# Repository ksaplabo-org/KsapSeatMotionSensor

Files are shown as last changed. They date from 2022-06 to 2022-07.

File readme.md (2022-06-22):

# SeatMotionSensor

## 目次  
- [全体概要](#content1)  
- [ESP32で人感センサの操作](#content2)  
- [Raspberry Piでデータ送受信](#content3)  
- [モノの作成](#content4)  
- [DynamoDBの作成](#content5)  
- [IAMロールの作成](#content6)  
- [Lambdaの作成](#content7)  
- [API Gatewayの作成](#content8)  
- [公開するWebアプリケーションの作成](#content9)  
- [S3での公開方法](#content10)  
- [残課題](#content11)  
- [感圧センサの利用](#content12)

<h2 id="content1">全体概要</h2>  

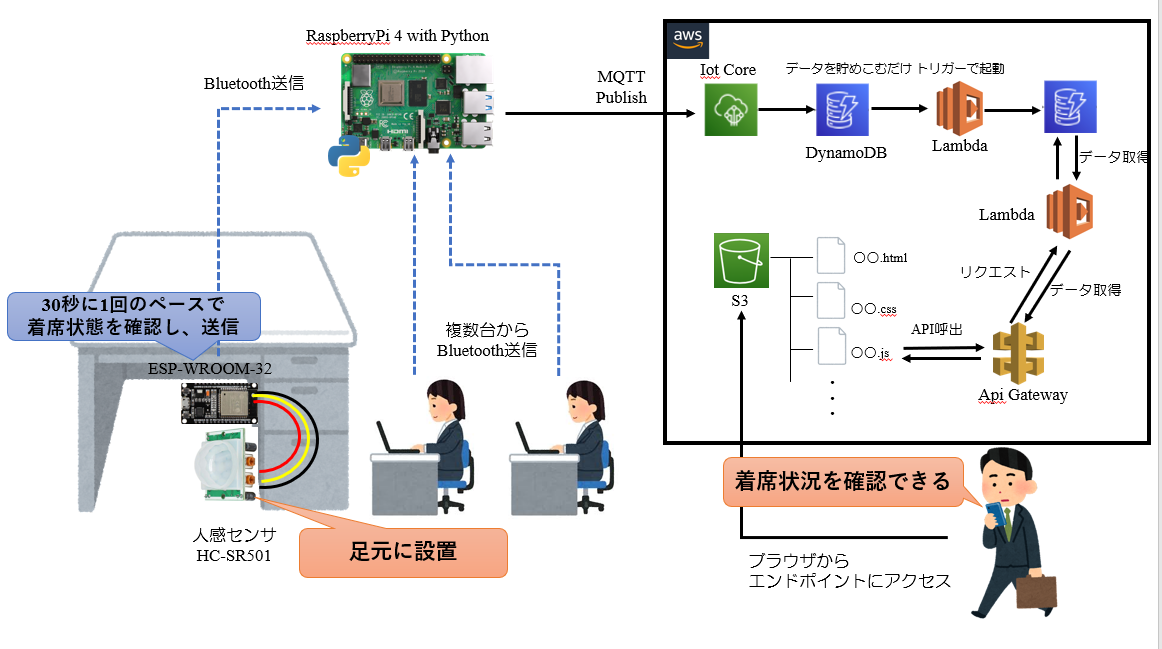
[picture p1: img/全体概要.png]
全景
  

支店管理部の在籍情報をリアルタイムで知ることができるシステムの開発  

※以下は人感センサを利用したシステムの説明を行う  
※一部ソースは感圧センサを利用したコーディングとなっているため  
  人感センサを利用したソースはHistoryから参照  

・システム説明  
図の左半分：管理部の座席足元に人感センサを設置して、席にいるかどうかをESP32でキャッチ  
           着席情報をRaspberry Piへ送信  
           それを受け取ったRaspberry PiがIoT Coreへパブリッシュする  

図の右半分：IoT Coreの受信をトリガーに、DynamoDBへ日時をキーとしてデータ登録  
           このデータ登録をトリガーとして、もう一つのDynamoDBに座席名をキーとしてデータ登録  
           S3の静的ホスティングサービスを使い、公開されたURLに利用者はアクセスする。  
           S3に保存してある、JavaScriptからAPIGateway、Lambdaを介して在籍情報を取得  
           データを成形して、ブラウザ上に表示する  

文章での説明では分かりずらいので、それぞれの機能実装手順を以下に示す  

<h2 id="content2">ESP32で人感センサの操作</h2>  

人感センサの仕組みについては[こちら](./%E6%8A%80%E8%A1%93%E8%AA%BF%E6%9F%BB.md)を参照  

ESP32と人感センサの配線は以下のように組む  
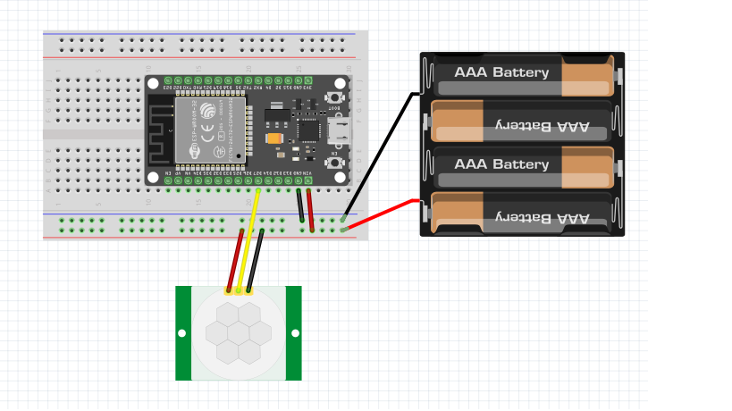
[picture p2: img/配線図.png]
配線図
  

ソースは以下のようになる  
[seatmotionsensor.ino](./ino/seatmotionsensor.ino)  

Arduino IDEを使用して、ソースをコンパイルする  
Arduino IDEの使い方は[こちら](https://github.com/ksaplabo-org/ksapDoorOpener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)を参照  

<h2 id="content3">Raspberry Piでデータ送受信</h2>  

Raspberry Piのセットアップは[こちら](https://github.com/ksaplabo-org/Raspi-Setup)を参照  

各ライブラリのインストールが必要  
- MQTT通信するためのライブラリ  
```
$ pip3 install paho-mqtt python-etcd
```
- bluetoothを使用するためのライブラリ  
```
$ sudo apt-get install python3-pip libglib2.0-dev
$ sudo pip3 install bluepy
```

ソースは以下のようになる  
[logget.py](./py/logger.py)  
[main.py](./py/main.py)  
[motion_detector.py](./py/motion_detector.py)  

<h2 id="content4">モノの作成</h2>  
 
Iot Coreで「モノ」の作成  
作成方法については[こちら](https://github.com/ksaplabo-org/aircondition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)を参照  
モノの名前は任意で作成  

MQTTテストクライアントで受信するとこを確認出来たら、DynamoDBの作成を行う  

<h2 id="content5">DynamoDBの作成</h2>

今回はDynamoDBを2つ用意する。  
1.受信したデータを全て登録するDynamoDB  
2.座席名ごとに着席情報を管理するDynamoDB  

1.受信したデータを全て登録するDynamoDB  

DynamoDBを作成方法は[こちら](https://github.com/ksaplabo-org/aircondition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)を参照  
今回作成するDynamoDB名は以下の通り ※名前は任意  
DynamoDB名：ksap-seatingstatehistory-tbl  

DynamoDBのコンソール画面から「テーブル」＞「項目の探索」を選択し  
作成したDynamoDBを選択  
「項目の作成」を選択して、以下のテストデータを作成  

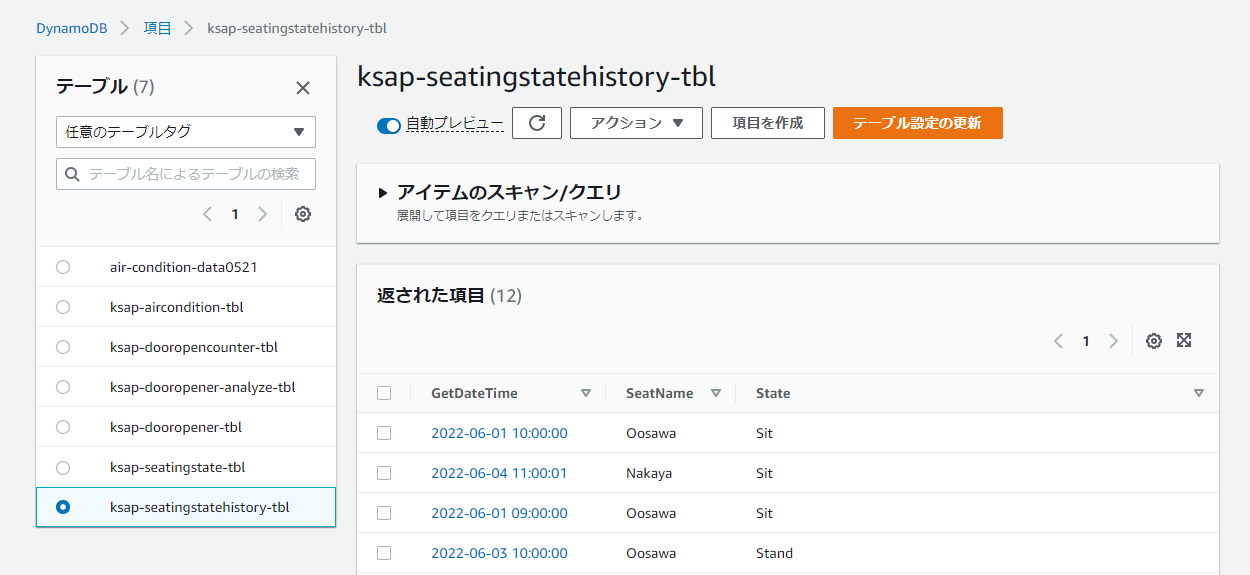
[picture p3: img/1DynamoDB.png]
1DynamoDB
  

項目名は任意だが、この後のソースでこの名前を使用するため後で迷わないように  

2.座席名ごとに着席情報を管理するDynamoDB  

1と同様の手順でテストデータまで作成  
DynamoDB名：ksap-seatingstate-tbl  

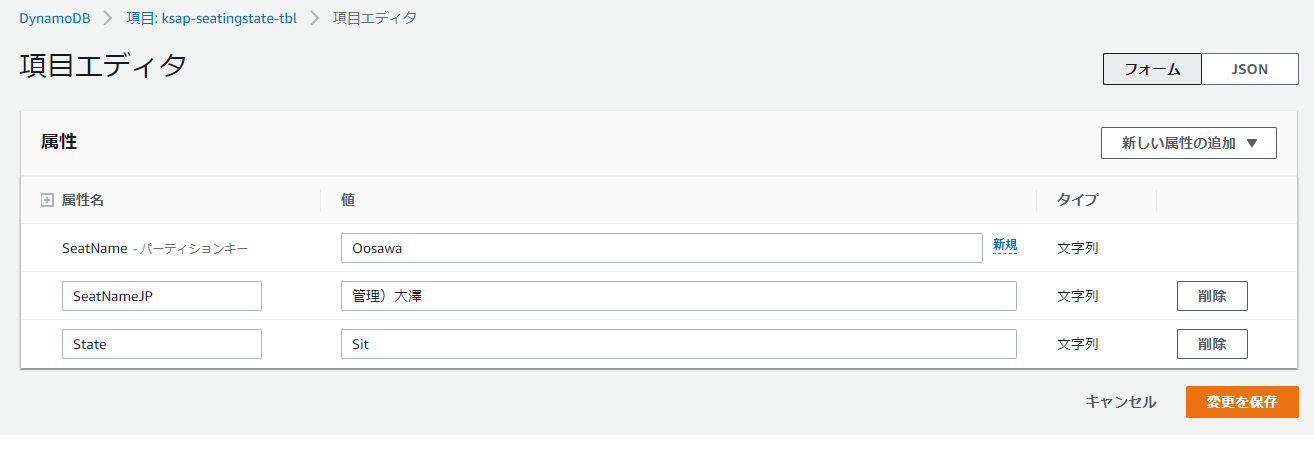
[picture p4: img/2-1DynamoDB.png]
2-1DynamoDB
  
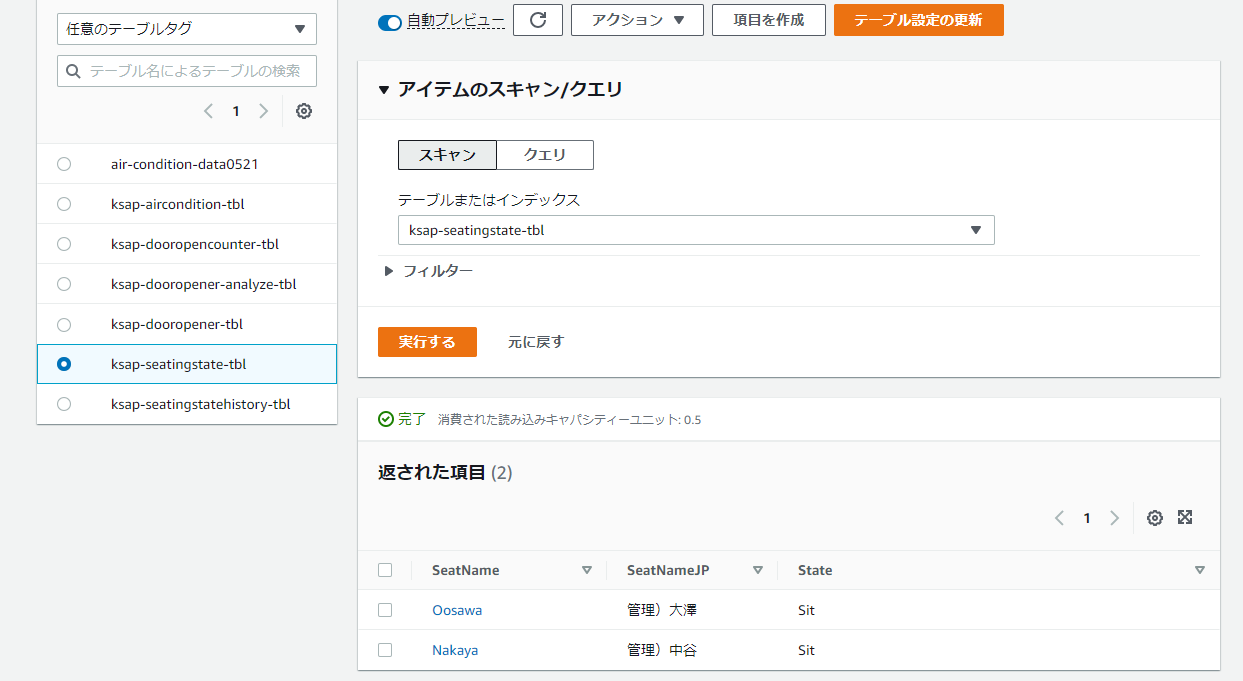
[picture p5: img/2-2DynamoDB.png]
2-2DynamoDB
  

<h2 id="content6">IAMロールの作成</h2>

LambdaがDynamoDBにアクセスするためのIAMロールを作成  

IAMコンソール画面の左ペインから「ロールを選択」  
「ロール」の設定画面から「ロールの作成」ボタンを選択  
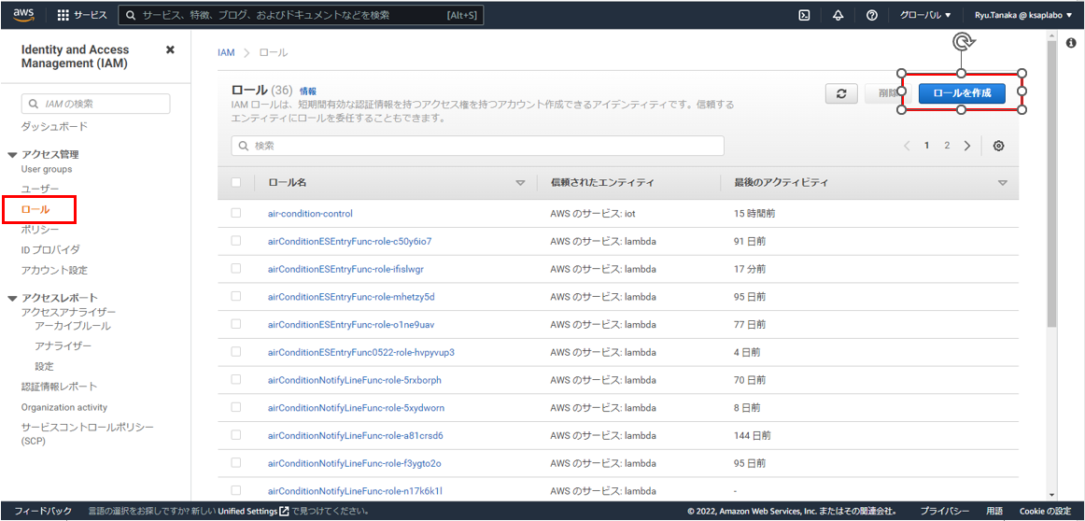
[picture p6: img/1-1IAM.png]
1-1IAM
  

「信頼されたエンティティタイプ」はデフォルトの「AWSのサービス」を選択  
「ユースケース」は「Lambda」を選択し、「次へ」を選択  
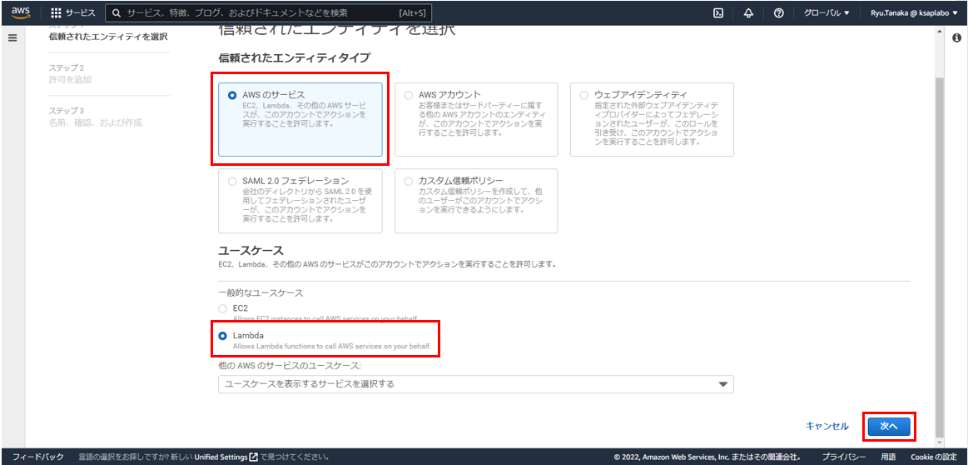
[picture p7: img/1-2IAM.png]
1-2IAM
  

「許可を追加」画面で以下の二つのポロしーを選択して、「次へ」を選択  
・AmazonDynamoDBFullAccess  
・AWSLambdaDynamoDBExecutionRole  
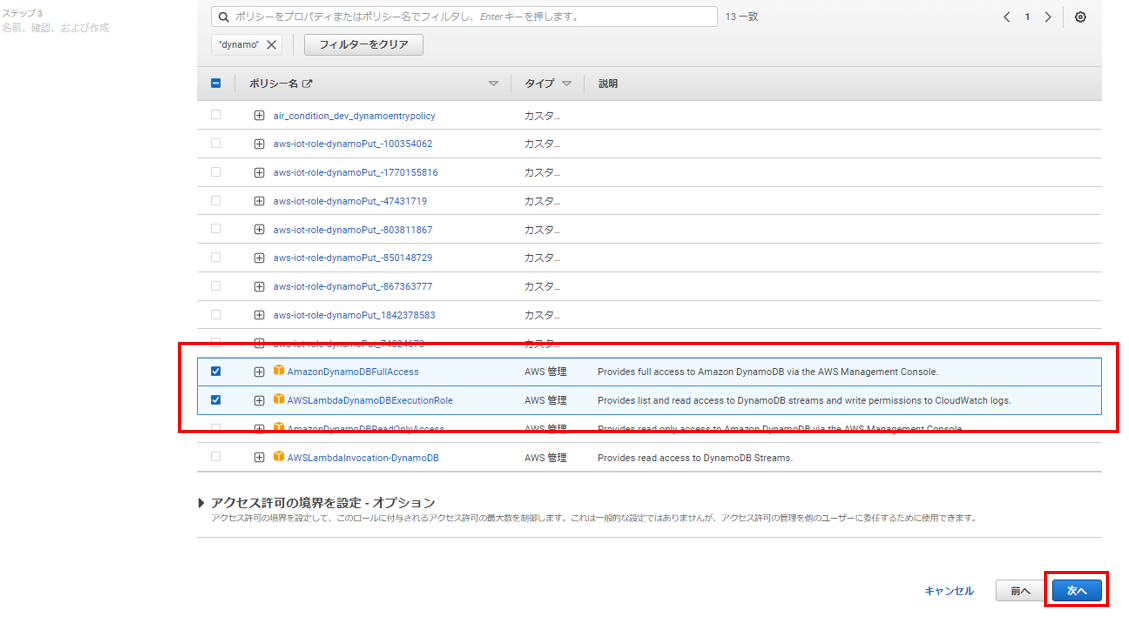
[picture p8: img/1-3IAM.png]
1-3IAM
  

「ロール名」に「LambdaAccess2DynamoDB」と入力し、右下の「ロールを作成」を選択  
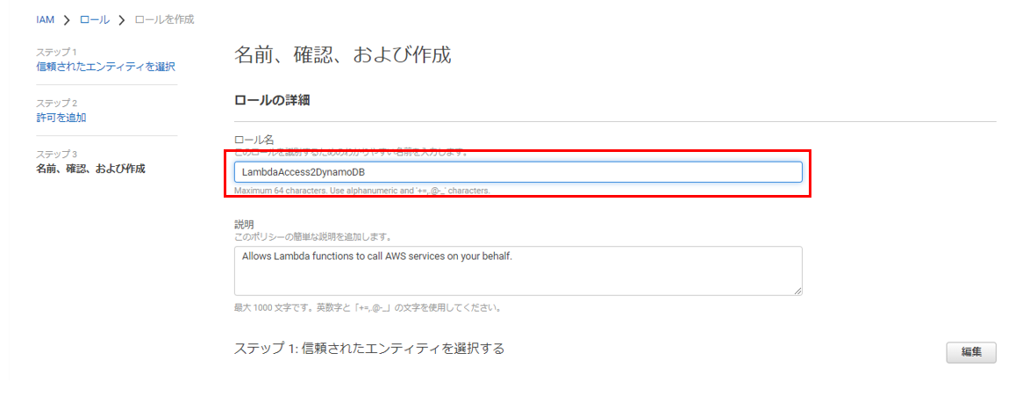
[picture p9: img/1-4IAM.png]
1-4IAM
  
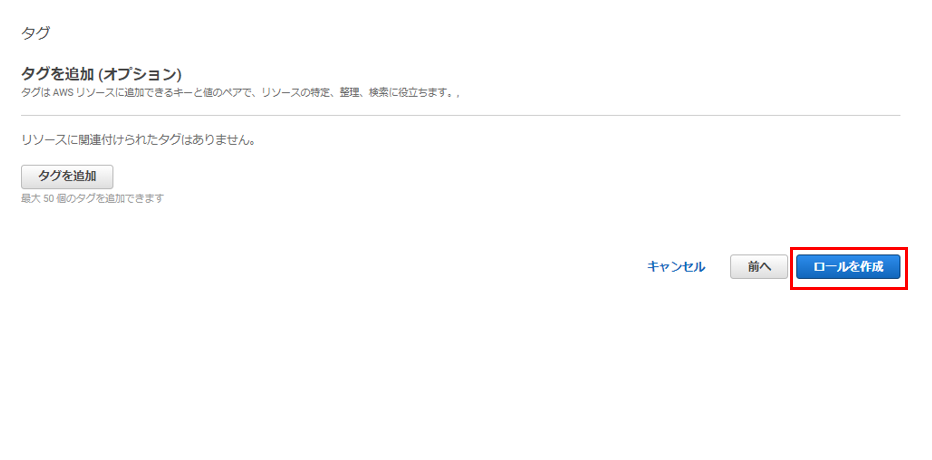
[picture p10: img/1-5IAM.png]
1-5IAM
  

ロールの作成が完了するとロールの一覧に「LambdaAccess2DynamoDB」が登録されます  
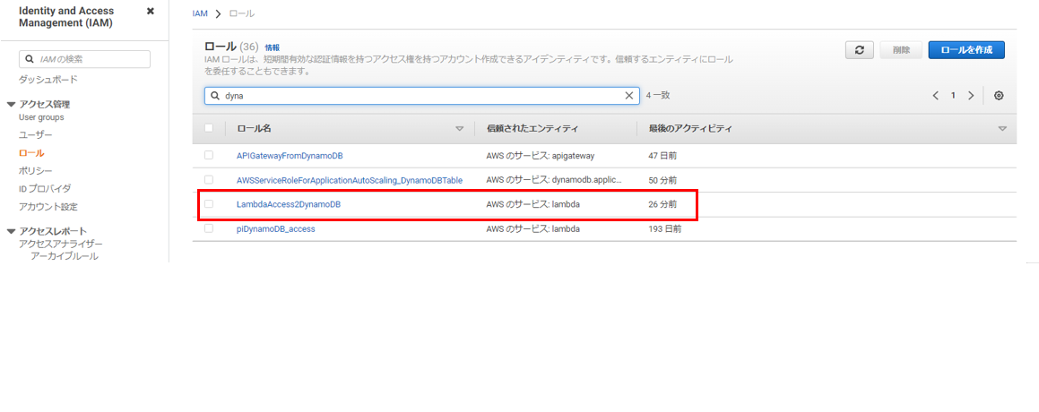
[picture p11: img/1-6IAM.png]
1-6IAM
  

<h2 id="content7">Lambdaの作成</h2>

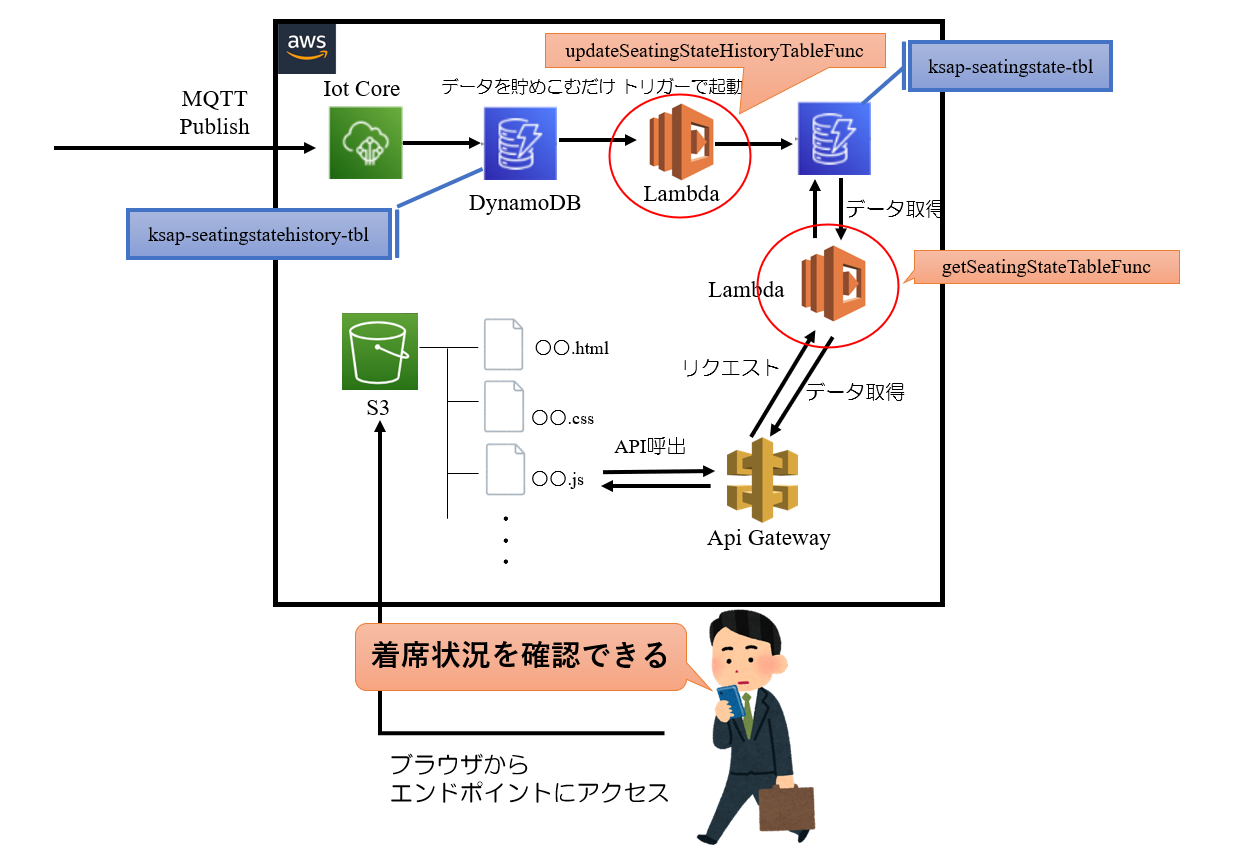
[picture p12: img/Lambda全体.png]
Lambda全体
  

Lambdaを2つ用意する  

1.ksap-seatingstatehistory-tblへのデータ登録をトリガーに  
SeatNameをキーにして、ksap-seatingstate-tblにデータをUpdateする関数  
(関数名：updateSeatingStateHistoryTableFunc)  

2.APIGatewayからのリスエストをトリガーに  
ksap-seatingstate-tblのデータを取得する関数  
(関数名：getSeatingStateTableFunc)  

1.updateSeatingStateHistoryTableFunc  

Lambdaコンソールから「関数の作成」を選択  
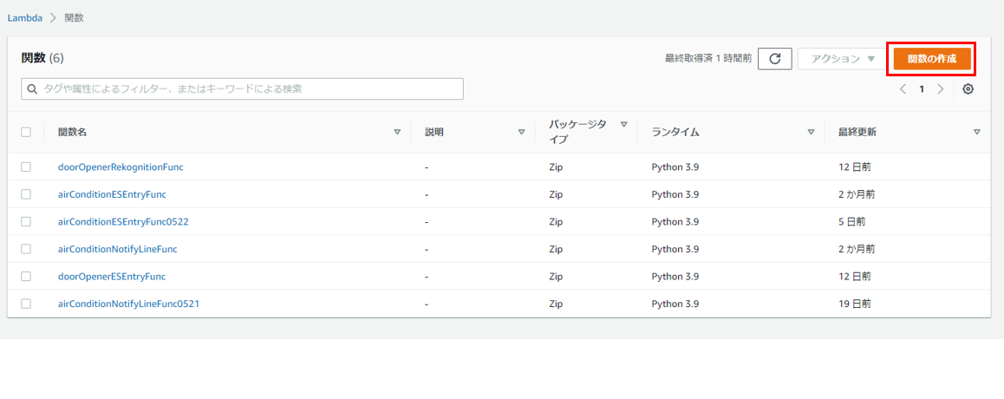
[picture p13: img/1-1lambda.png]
1-1lambda
  

オプションはデフォルトの「一から作成」を選択  
関数名は「updateSeatingStateHistoryTableFunc」を入力  
ランタイムは「Python3.9」を選択  
アーキテクチャはデフォルトのまま  
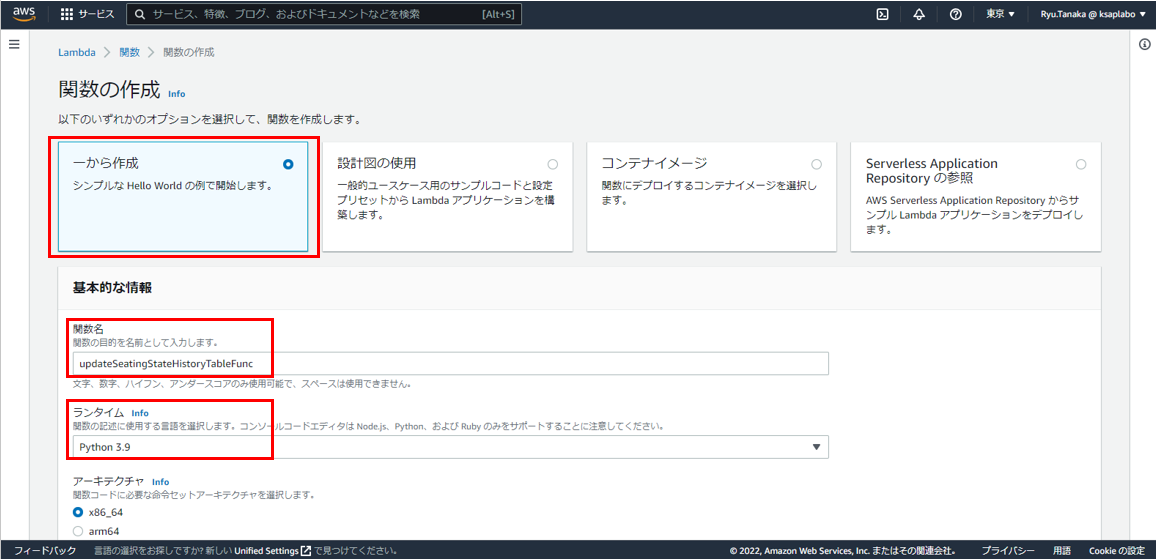
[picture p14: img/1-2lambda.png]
1-2lambda
  

「デフォルトの実行ロールの変更」を開き  
「既存のロールを使用する」を選択  
既存ロールの一覧から先ほど作成した「LambdaAccess2DynamoDB」を選択  
詳細設定はそのままで、関数の作成を選択  
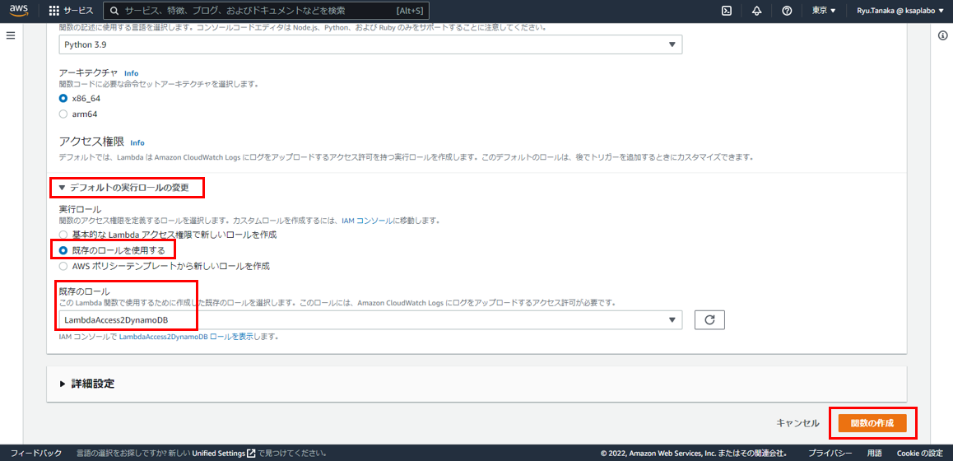
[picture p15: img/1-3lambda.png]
1-3lambda
  

「コードソース」に以下のソースをコピーして貼り付けする  
[updateSeatingStateHistoryTableFunc.py](./lambda/updateSeatingStateHistoryTableFunc.py)  
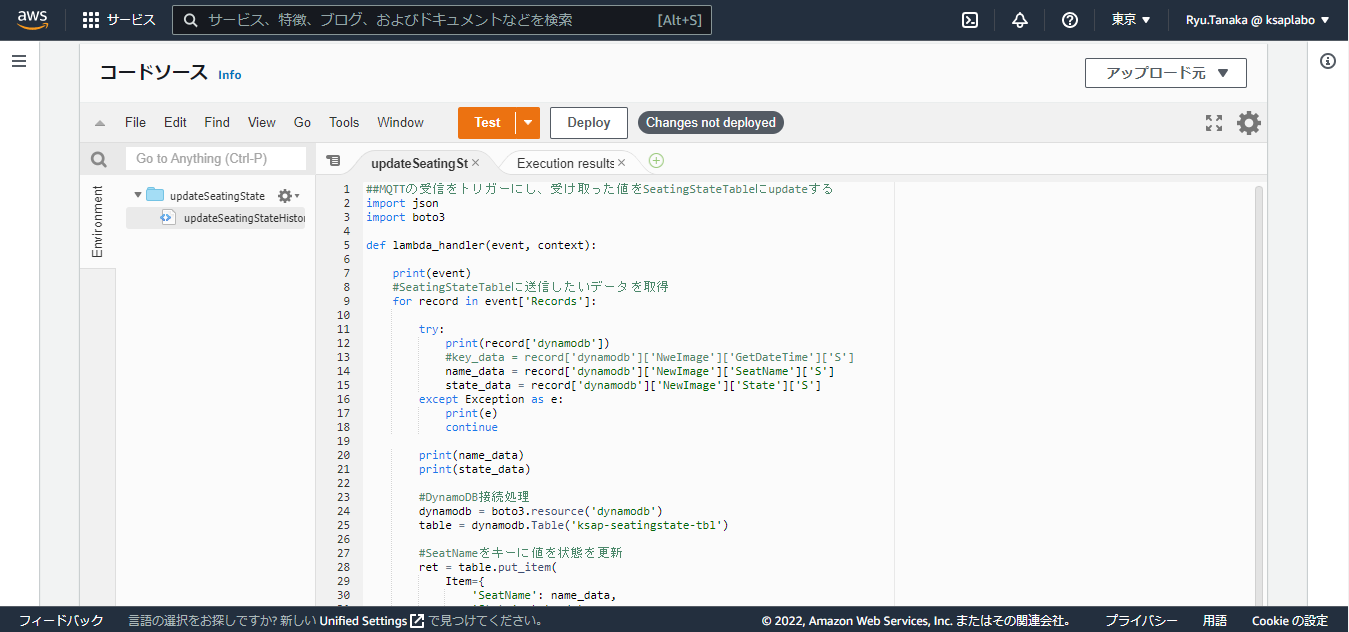
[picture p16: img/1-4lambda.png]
1-4lambda
  

ソースを作り終えたら、トリガーの設定を行う  
「設定」タブを選択し、「トリガーを追加」を選択  
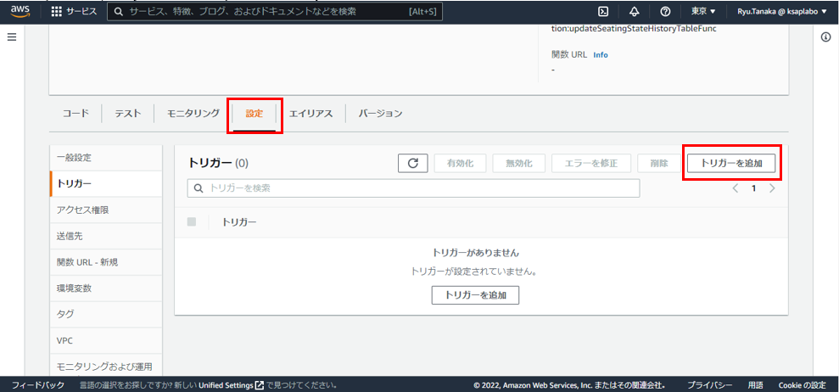
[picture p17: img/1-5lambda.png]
1-5lambda
  

「トリガーを選択」のプルダウンから「DynamoDB」を選択し  
「DynamoDBテーブル」は「ksap-seatingstatehistory-tbl」を選択  
後の設定はデフォルトのまま、右下の「追加」を選択  
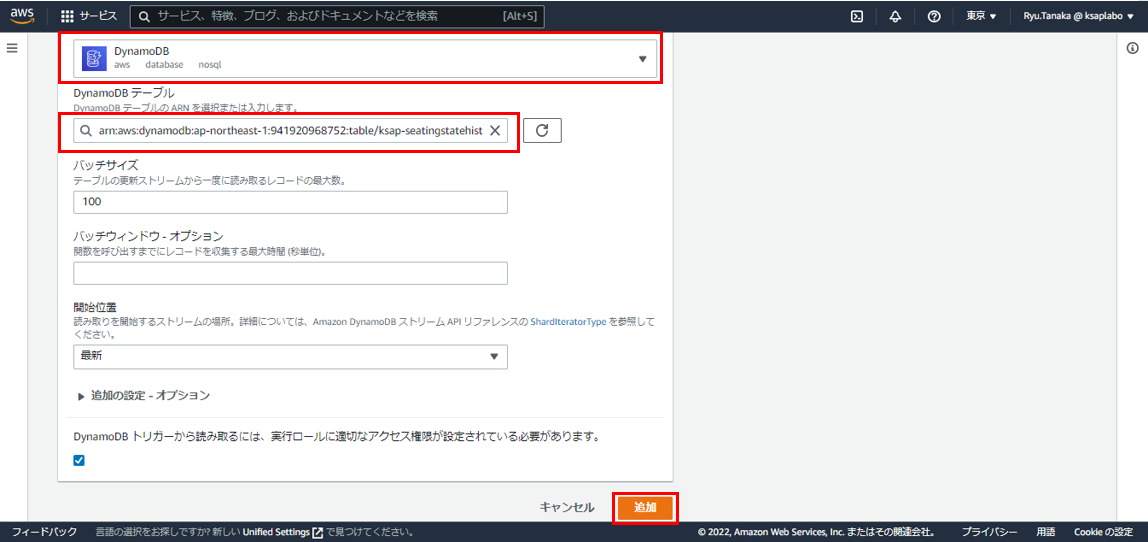
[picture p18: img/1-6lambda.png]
1-6lambda
  

関数の定義画面に戻るので、そこでDynamoDBがトリガーに追加されています  
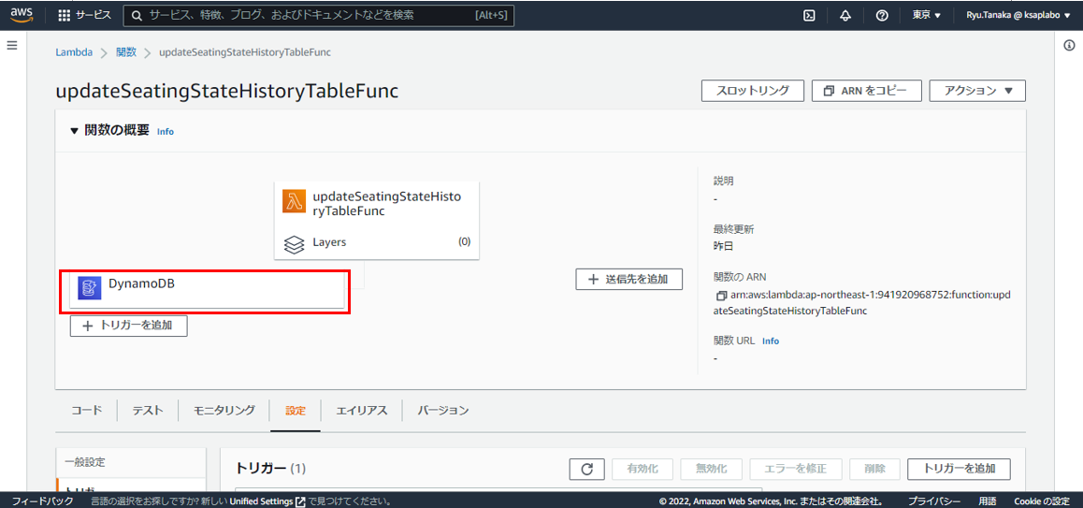
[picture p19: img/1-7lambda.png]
1-7lambda
  

以上で1つ目の関数の作成は終わり  

<br>
2.getSeatingStateTableFunc  

updateSeatingStateHistoryTableFuncと同様の出順で作成  
※関数名「getSeatingStateTableFunc」とする  
※トリガーにDynamoDBの登録はしません  
以下のソースをコピペしてください  
[getSeatingStateTableFunc.py](./lambda/getSeatingStateTableFunc.py)  

<h2 id="content8">API Gatewayの作成</h2>

lambda関数「getSeatingStateTableFunc」へリクエストするためのGatewayを作成します  

コンソール画面から「APIを作成」を選択  
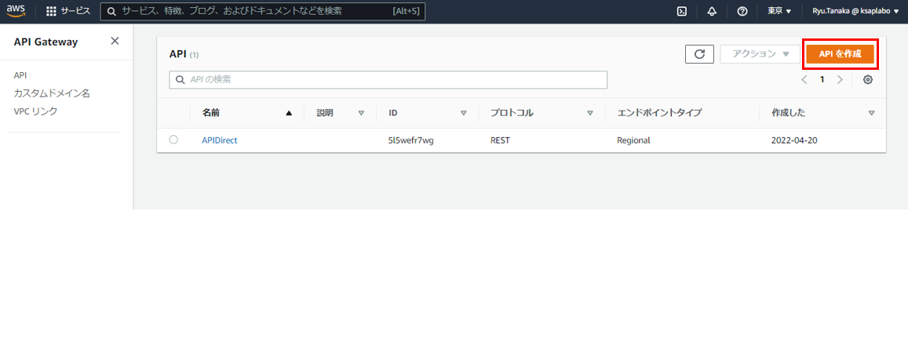
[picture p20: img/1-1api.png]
1-1api
  

APIタイプを選択の中の上から3つ目の「REST API」を選択  
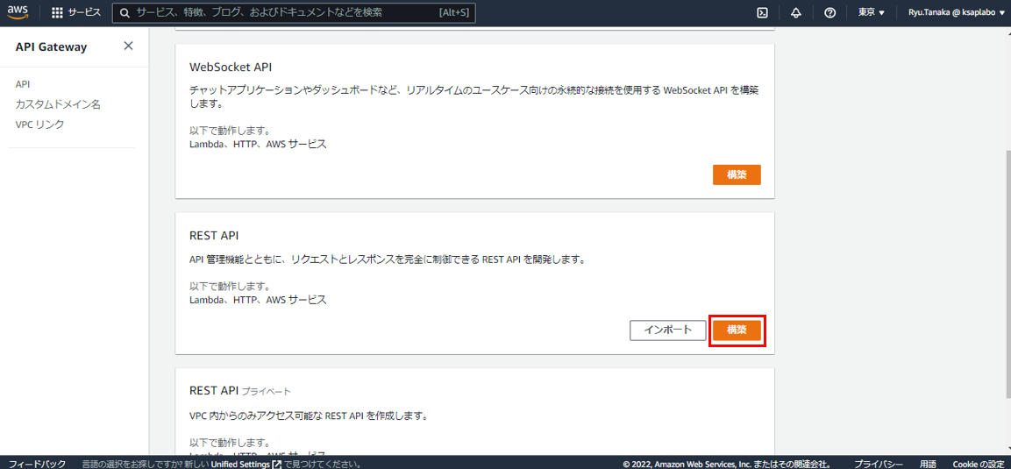
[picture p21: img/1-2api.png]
1-2api
  

API名を「SeatMotionAPI」とし、他の設定はデフォルトのまま「APIの作成」を選択  
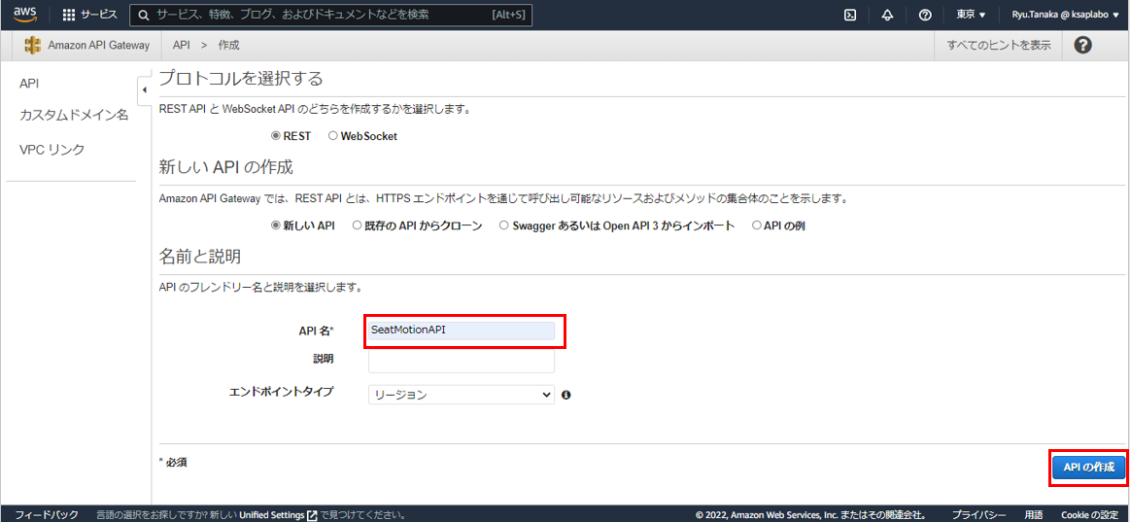
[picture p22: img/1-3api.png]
1-3api
  

画面が遷移したら、アクションから「リソースの作成」を選択　　
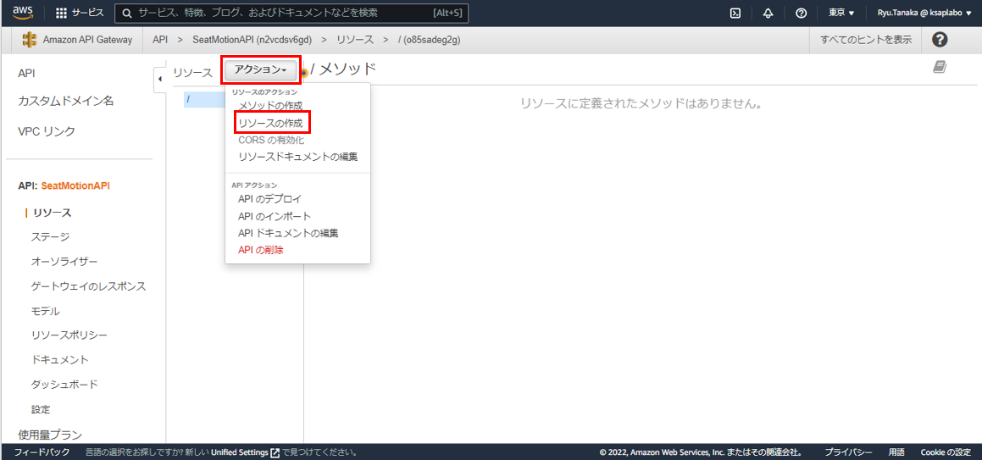
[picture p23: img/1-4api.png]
1-4api
  

リソース名を「SeatMotionResource」にし、「リソースの作成」を選択  
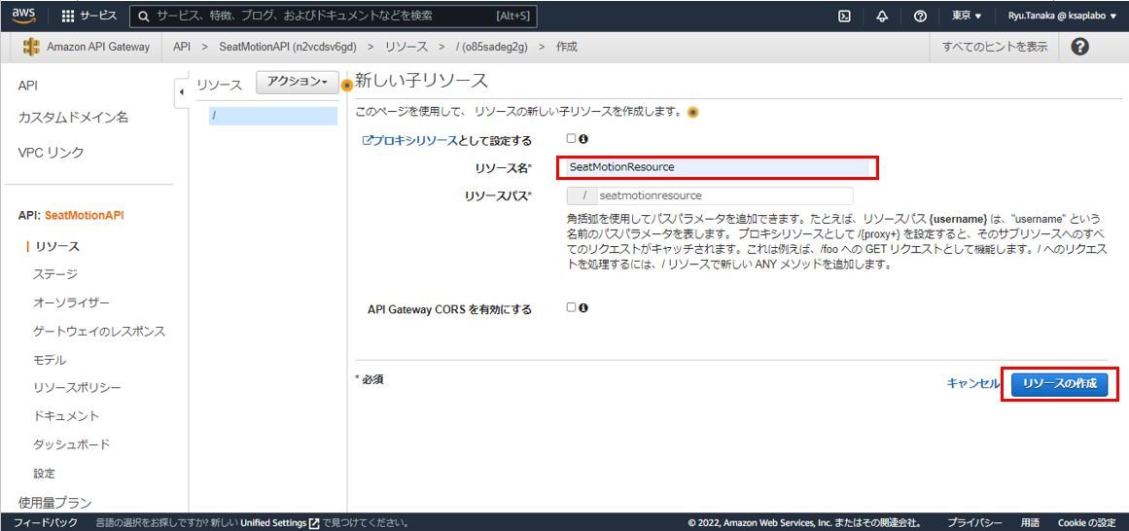
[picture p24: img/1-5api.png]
1-5api
  

アクションから「メソッドの作成」を選択し、プルダウンの中から「POST」を選択  
選択すると、横にチェックマークが出てくるので、チェックマークをクリックする  
すると、以下の画面が出てくるので、Lambda関数のところに「getSeatingStateTableFunc」と入力し  
「保存」を選択する　　
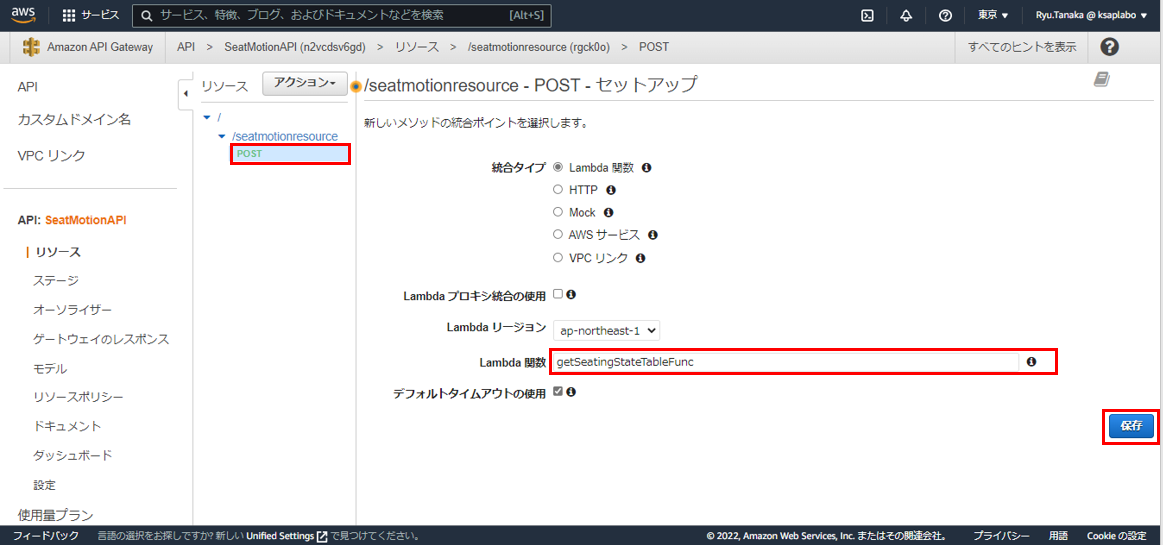
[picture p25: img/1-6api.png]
1-6api
  

「Lambda関数に権限を追加する」というダイアログが出てくるので、「OK」をクリック  

アクションから「CORSの有効化」を選択し、「CORSを有効化して～～」を選択する  
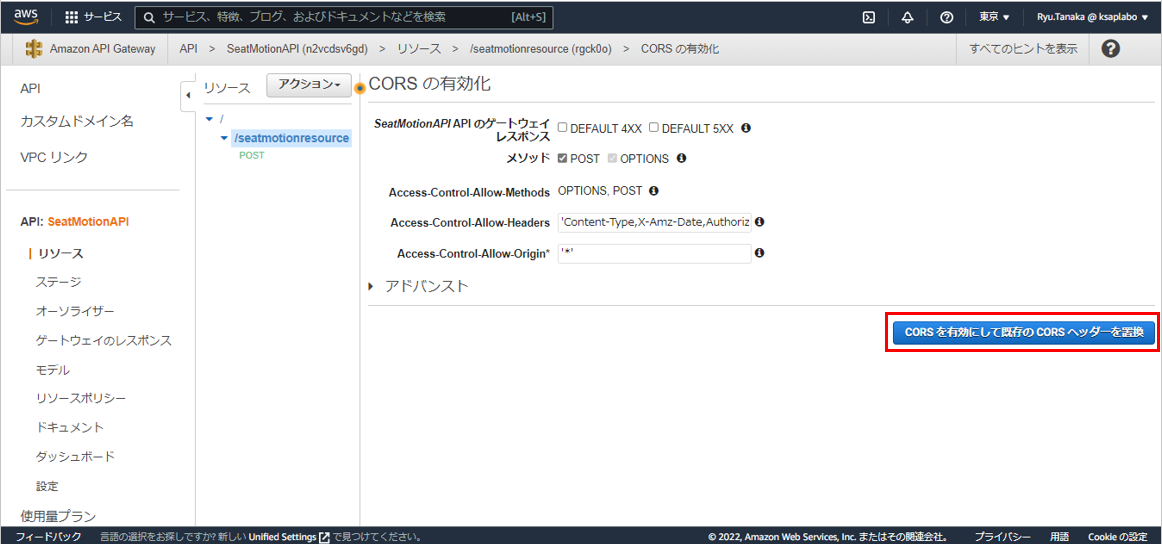
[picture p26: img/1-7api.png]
1-7api
  

「メソッド変更の確認」ダイアログが表示されるため、「はい、既存の値を置き換えます」をクリック  

リソースツリーで「POST」を選択している状態で、右の「統合リクエスト」を選択  
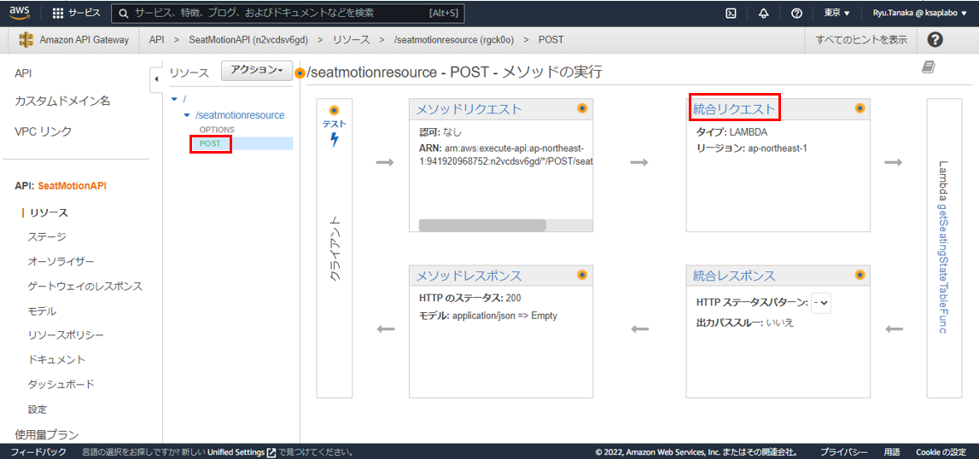
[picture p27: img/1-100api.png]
1-100api
  

下の方に「マッピングテンプレート」があるので、そこを選択し  
リクエスト本文のパススルーで、「テンプレートが定義されていない場合（推奨）」を選択  
「マッピングテンプレートの追加」を選択し、テキストに「application/x-www-form-urlencoded」を入力し
チェックマークをクリックする  
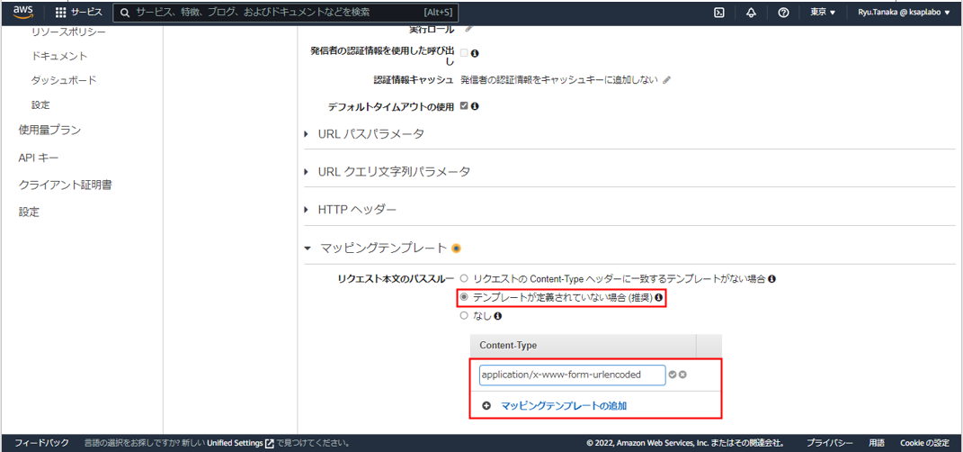
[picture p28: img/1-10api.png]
1-10api
  

テンプレートの生成は「メソッドリクエストのパススルー」を選択し、「保存」をクリック  
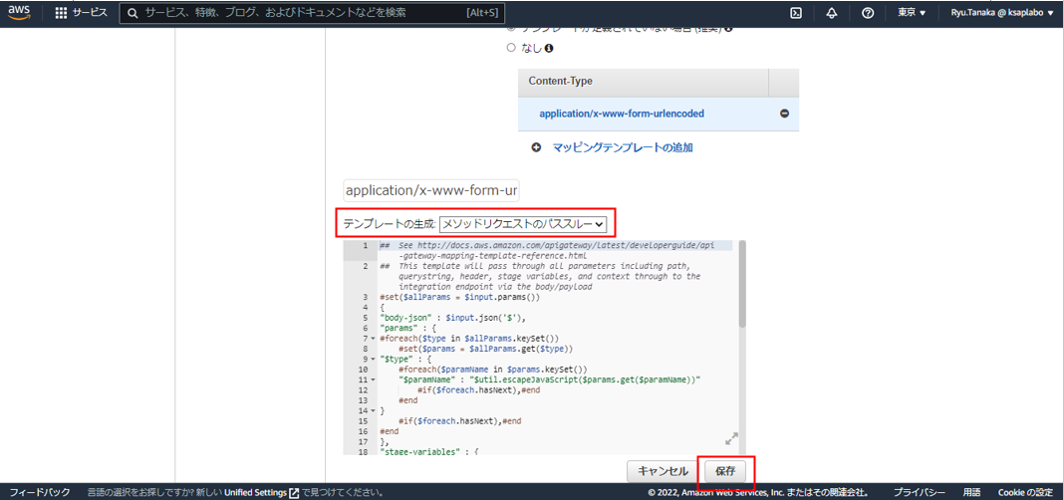
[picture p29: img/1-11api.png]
1-11api
  

アクションから「APIのデプロイ」を選択するとダイアログが表示されるので  
「デプロイされるステージ」欄に「[新しいステージ]」を選択  
「ステージ名」を「APIseatstage」にし「デプロイ」をクリックする  
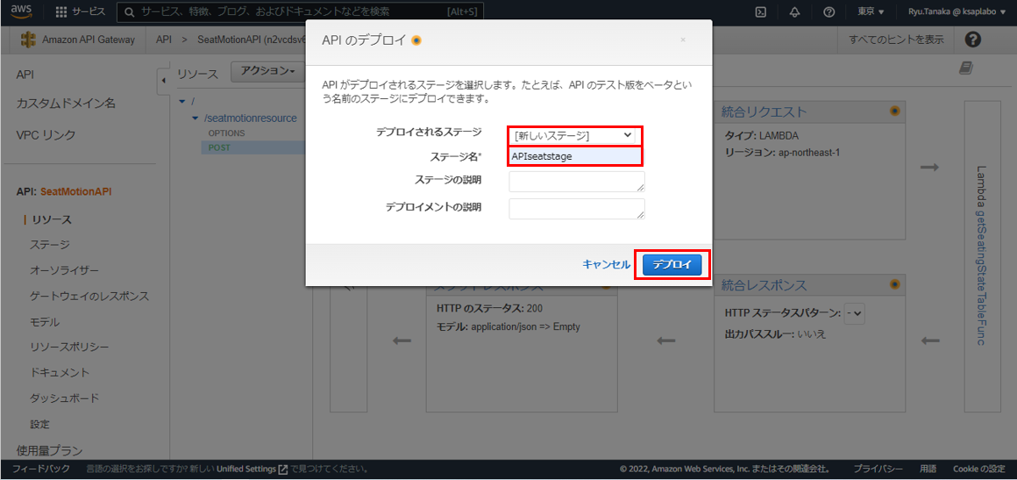
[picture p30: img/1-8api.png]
1-8api
  

APIseatstage ステージエディターにあるURLは後で使用するため、コピーしておく  
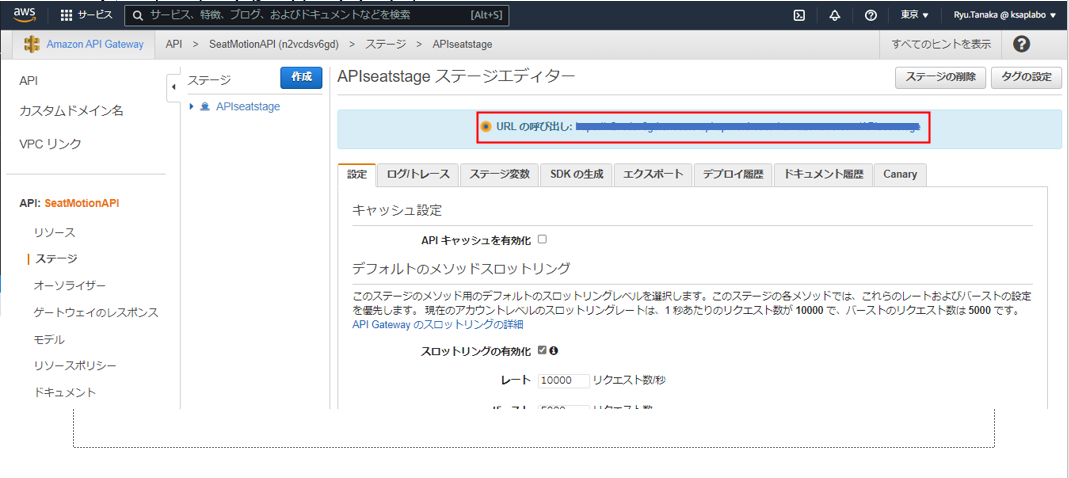
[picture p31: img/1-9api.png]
1-9api
  

<h2 id="content9">公開するWebアプリケーションの作成</h2>  

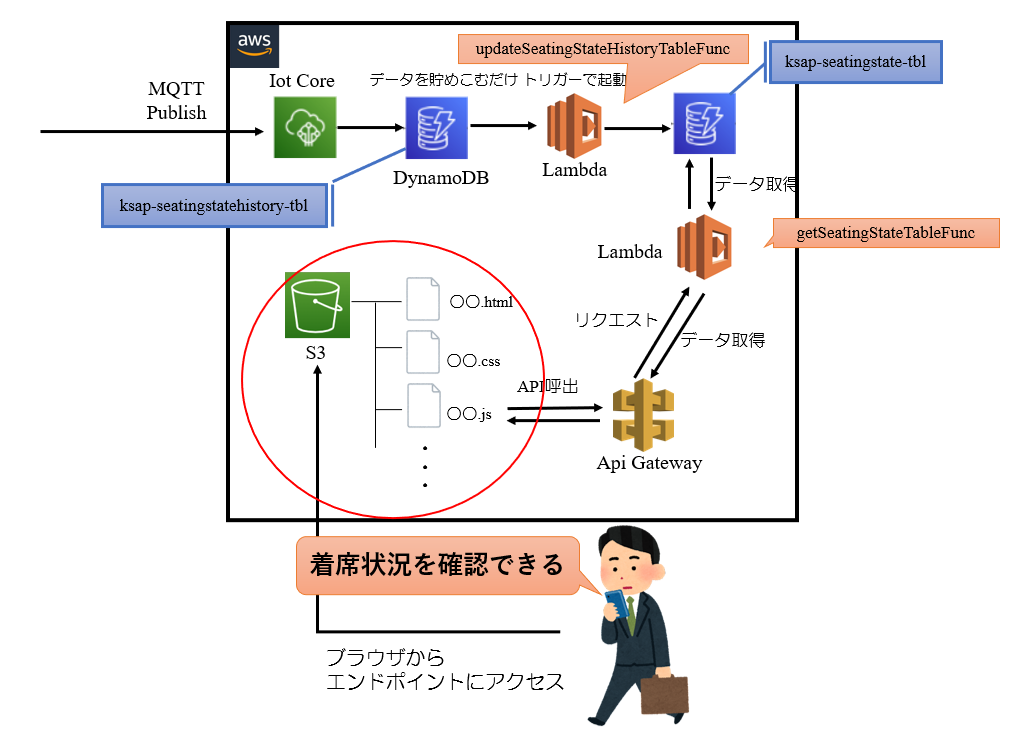
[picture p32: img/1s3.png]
1s3api
  

S3の静的ホスティングサービスを使用して公開するソースを作成する  

- html  
ソースはこちら[SeatingInfo.html](./ksap-seatmotion/SeatingInfo.html)  

- css  
ソースはこちら[style.css](./ksap-seatmotion/assets/css/style.css)  

- img  
状態更新表示用の画像[img](./ksap-seatmotion/assets/img/)

- javascript
ソースはこちら[main.js](./ksap-seatmotion/assets/js/main.js)  
ソースはこちら[subMain.js](./ksap-seatmotion/assets/js/subMain.js)  

ファイル構成はこのようになる  
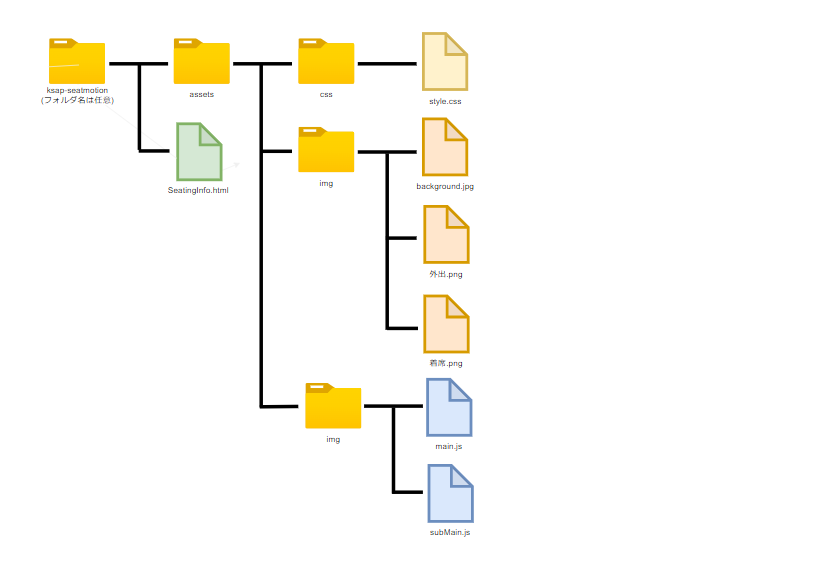
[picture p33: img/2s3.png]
2s3
  

これをS3上で公開する  

<h2 id="content10">S3での公開方法</h2>  

<h2 id="content11">残課題</h2>  

#### システムの精度が悪い  

座っているのに「外出」と表示されることがある  
→人感センサ（モーションセンサ）を使っているため、動きがないと検知できない  

#### テレワーク時はテレワークしていることを分かるようにしたい  

公開するHTMLを2種類用意  
・在席確認画面(いまあるやつ→SeatingInfo.html)  
・テレワーク登録画面付き在席確認画面(新しく作る)  

管理部の人たちには登録できる画面を公開し、一般には閲覧用の画面教える  

### 乾電池を利用したESPの起動時間が短い  

調査によると、単三電池3本では4日ほどしかESPは起動しない  

<h2 id="content12">残課題解決</h2>  

### システム精度の問題  

感圧センサを利用することで解決した  
システム構成図は[こちら](https://github.com/ksaplabo-org/KsapSeatMotionSensor/blob/master/external%20specification.md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)を参照  

ESP32と感圧センサの配線図を以下に示す  
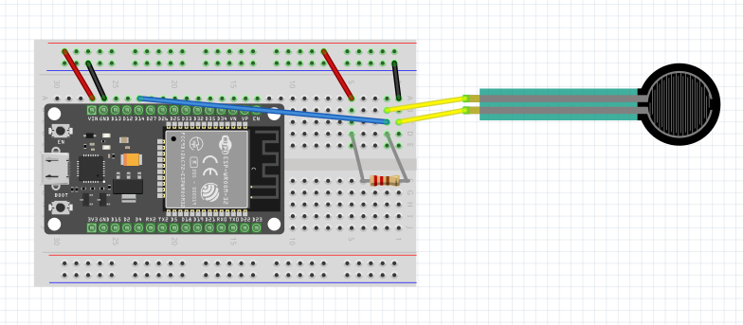
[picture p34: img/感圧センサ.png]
感圧センサ
  

ソースは以下を参照  
[BLE_EddystoneTLM_Beacon.ino](./ino/BLE_EddystoneTLM_Beacon.ino)  

感圧センサを使うことにより、着席情報を動体検知ではなく圧力検知になったため  
着席情報を取得する精度が上がった  

### テレワークボタンを追加  

公開するWeb画面を管理者用と閲覧者用に分け、管理者用の画面にテレワークボタンを追加した  
機能については[こちら](https://github.com/ksaplabo-org/KsapSeatMotionSensor/blob/master/external%20specification.md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)を参照

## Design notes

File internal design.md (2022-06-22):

# 内部設計  

## IoTデバイス
|デバイス名|役割|
|---|---|
|Raspberry Pi 4 model B|ESP32からの受信を行い、データをMQTTでパブリッシュする|
|ESP32|センサと接続し、取得したデータをBLEBeaconでRaspberry Piに向け送信する|
|感圧センサ(ALPHA-MF02-N-221-A01)|椅子に圧力がかかっているかを検知する|

## AWS周辺  

### DynamoDB  

|DynamoDB名|パーテンションキー|DBの役割|
|---|---|---|
|ksap-seatingstate-tbl|SeatName|各人の着席状態を保持|
|ksap-seatingstatehistory-tbl|GetDatetime|ESPからのデータを保持|
|ksap-seatingmaster-tbl|EspMacAddress|ESPのMACアドレスに対応した座席名を保持|  

### Lambda  

|関数名|役割|
|---|---|
|updateSeatingStateHistoryTableFunc|MQTTの受信をトリガに、データをksap-seatingstate-tblにupdateする<br>また、受信したESPのMACアドレスをキーにksap-seatingmaster-tblへ接続し、座席名を取得する|
|getSeatingStateTableFunc|リクエストで起動し、ksap-seatingstate-tblの値をscanし返却する|  

### Api Gateway  

|API名|役割|
|---|---|
|SeatMotionAPI|Web画面とLambdaの架け橋となり、リクエストを受けたらLambdaにリクエストを行う|  

### S3  

Webページの公開はHTTPSで行う

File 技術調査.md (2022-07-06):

## 人感センサ(HC-SR501)について

人感センサといいつつ、実はモーションセンサーで、センサーの範囲内でモノが動かないと  
検知を行わない  

電源は4.5~20V(ESP32から5.0V出力可能)

つまみが二つ付いていて  
一つはセンサー感度で、センサーが感知する処理を設定できる(3~7m)  
もう一つは時間調整で、センサーがONになった時、ONを維持する時間を調整できる(5~200s)  

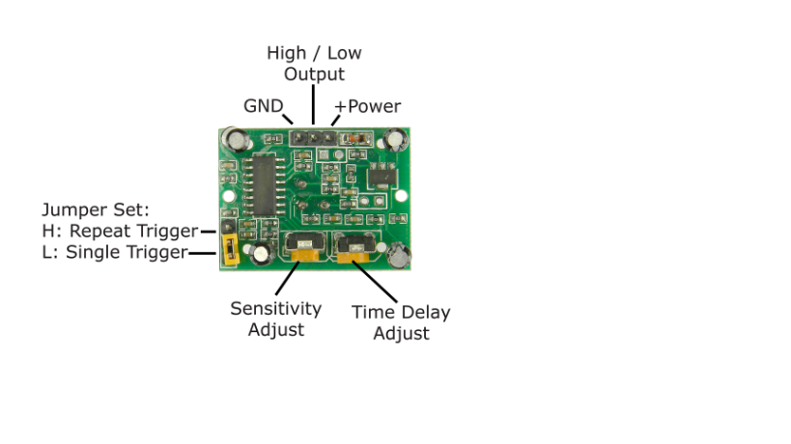
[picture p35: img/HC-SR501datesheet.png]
A
 

一番左に回すと、一番小さい値になるため、どちらも最小にすると  
感度:3m  
時間:5s 

試しに動かしてみる  
→検知する時間は最小で5秒とあるが、実際に動かしてみると、1秒くらいでも検知している  

参考：https://hellobreak.net/raspberry-pi-hc-sr501-0912/  

## 試作  

足元に人感センサ(HC-SR501)を設置して、反応があれば、Raspberrypiでキャッチする  
→できた  
ESP32でも試してみる  
→できた  
ESP32の電源を単三電池3本で試してみる  
→たぶんできてる（外部的な確認ができていない）  

## S3について  

```
S3とはデータを格納・管理できるオブジェクトストレージサービスです。
```

### S3でHTMLを公開  

以下のサイトを参考にやってみる  
https://qiita.com/d-yoshizaki-sss/items/c50ec1e30a08d72c2dec

test.htmlを公開することができた  
アップロードするファイル名を「index.html」にするとうまくいかない  

### 公開したHTMLにJavascriptを実行させる  

- SDK(Software Development Kit)
```
あるシステムに対応したソフトウェアを開発するために必要なプログラムや文書窓をひとまとめにしたパッケージ
```

scriptタグを設定すればJavascriptの実行はできた  
→test.html

## 参考になりそうなサイト  

- S3,DynamoDB,Lambda,API Gatewayを利用したクラウドサービスの作成  
https://qiita.com/skikuchi1030/items/b27384d3f7589c3556b5  

S3のバケット名：ksap-seatmotionsensor  

DynamoDBに項目を増やす方法  
テーブル＞項目の探索から右上の「項目を作成」ボタンから可能  

→API Gateway辺りで分からなくなる  

## LambdaとAPI Gatewayの使い方  

参考サイト  
https://business.ntt-east.co.jp/content/cloudsolution/column-try-20.html#section-04  

今のアカウントだと、APIが作成できない  

→APIGatewayを作成して、このサイト通りのことはできた  

## 静的ホスティングをHTTPSで実現する方法  
S3のバケット名がksap-staticwebpagesのバケットに、自分のフォルダをアップロードして  
福島さんのURLの最後の部分の名前を自分のフォルダ名にしたら、HTTPSになる

## GETとPOSTの違い  
大きな違いは 
・GET  ページを「取得」するためのリクエスト  
・POST 情報を「送信」するためのリクエスト  
参考：https://blog.senseshare.jp/get-post-method.html  

## S3のドメイン（福島さんのファイルフォルダ）情報  
https://d17rjxxyw6f0pl.cloudfront.net/  
この後ろに自分のフォルダ名をつける  
https://d17rjxxyw6f0pl.cloudfront.net/ksap-seatmotion/SeatingInfo.html

## 髙田さんからの参考URL  
https://qiita.com/tanj/items/e4486f9af5d7a903117d  
→これ通りやるとできた  

## 電池残高
|席名|残量（V）|
|---|---|
|O.S|7/4 09:00 5.88<br>7/4 18:17 5.42V<br>7/5 08:49 5.18V<br>7/5 18:07 5.03V<br>7/6 08:55 4.74V<br>7/6 18:00 4.70V|
|N.Y|7/4 09:00 5.18<br>7/4 18:17 4.65V<br>7/5 08:49 3.75V<br>7/5 18:07 3.00V(停止) |
|O.M|7/4 09:00 5.94<br>7/4 18:09 5.23V<br>7/5 08:49 4.67V<br>7/5 18:07 3.88V(ほぼ停止)|

## 人感センサの代わりに感圧センサを使ってみる  

このサイトを参考に行ってみた  
https://toccho.net/2021/11/13/esp32-pressure/  

ESP32が38ピン用を使っていたので、今手元にある30ピン用にピン配置を変えて実行してみた  
→うまくいった

ワニ口のジャンプワイヤが欲しい  

## （大澤さん）テレワークかどうかも分かりたい  

画面上でテレワークしているかどうかも分かりたいとのリクエストがあったので、試みる  

URLにパラメータを持たせることができるかを確認する  
→S3でもURLの後ろに？を付けるとパラメータを設定できる  
 Javascriptでdocument.location.search.substring(1)  
 ではてなをのぞいた文字列を取得できる  

→テレワーク用ボタンを追加  
 提供するURLが管理者と閲覧者で変わる  
 閲覧者：～～  
 管理者：～～?management  

 ボタンを押すと、テレワークのアイコンに変化、テレワーク中は着席状態を更新しない  
 ボタンを押さない限りテレワークから状態は変更しない  
 テレワーク解除後は、離席で表示される  
 
 ## 電池耐久テストのための事前調査  
- ESPがいつ落ちるかわかるようにする  
  ESP-ラズパイ間の通信は常に行われているので、ラズパイでデータを受け取った時の時間をログとかでためておく  
　→openメソッドを使ってできた  

- ESPの電池残量をグラフ化する  
  そういうやり方があるらしい  

- DeepSleep機能を入れる  
  5秒動かして、55秒DeepSleepにする予定  
  →できた

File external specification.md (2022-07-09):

# 外部使用  

## システム構成図  

- 人感センサを利用したシステム構成図  

全景  

- 感圧センサを利用したシステム構成図（AWS側も少し変更）  

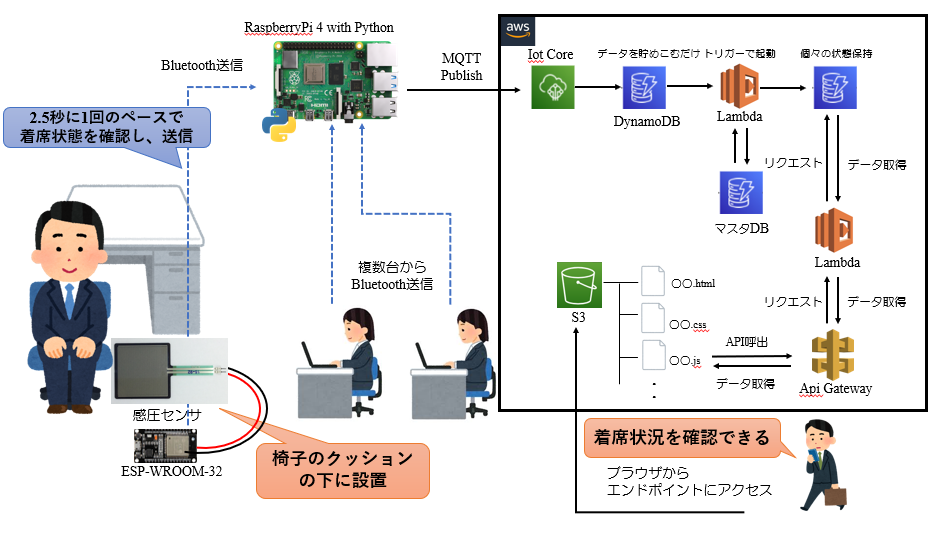
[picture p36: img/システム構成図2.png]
システム
  

以下、感圧センサを利用したシステムの外部使用を説明する  

## 椅子の状況  

クッションの下にESP32に接続された感圧センサを設置する  
ESP32は乾電池4本で動作  

  座席の裏にESP32を貼り付け（電池駆動）
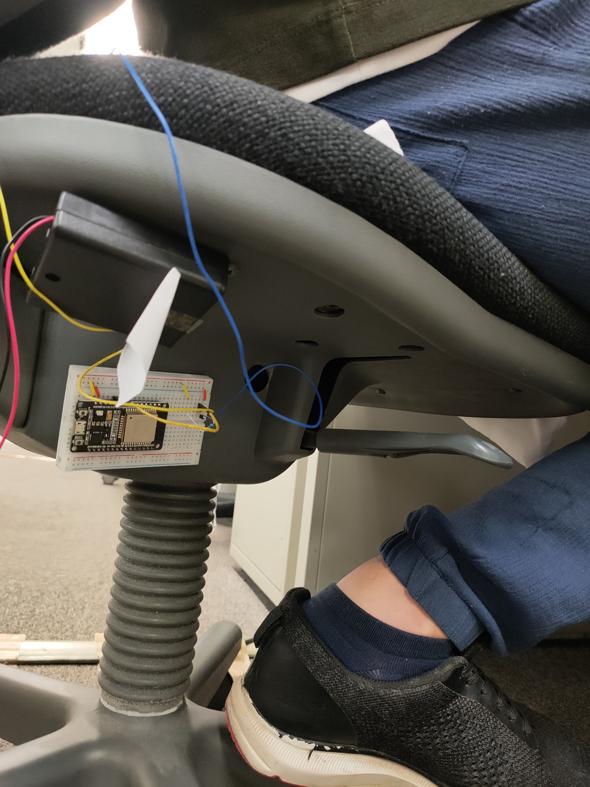
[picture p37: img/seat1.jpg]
seat1
    
  座席に座布団を引いて・・・
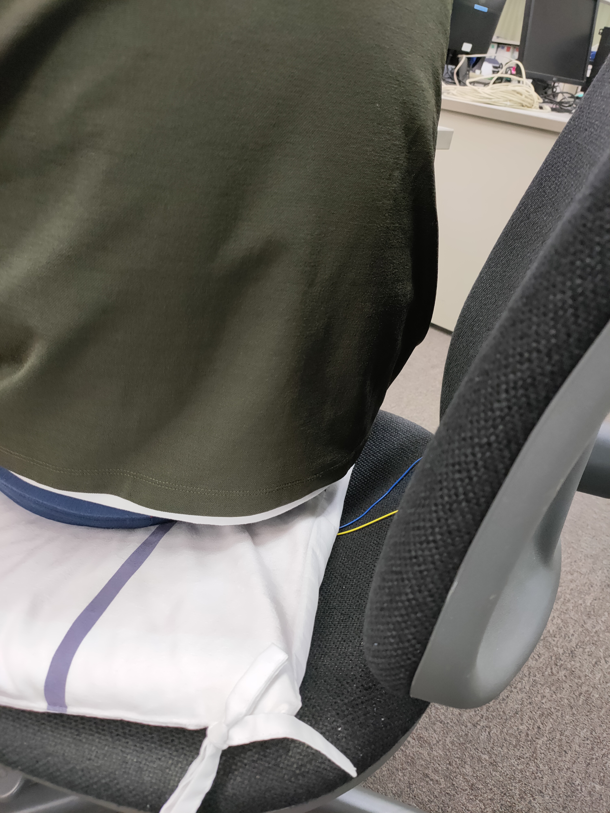
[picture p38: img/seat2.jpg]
seat2
  
  その裏に感圧センサーを配置 
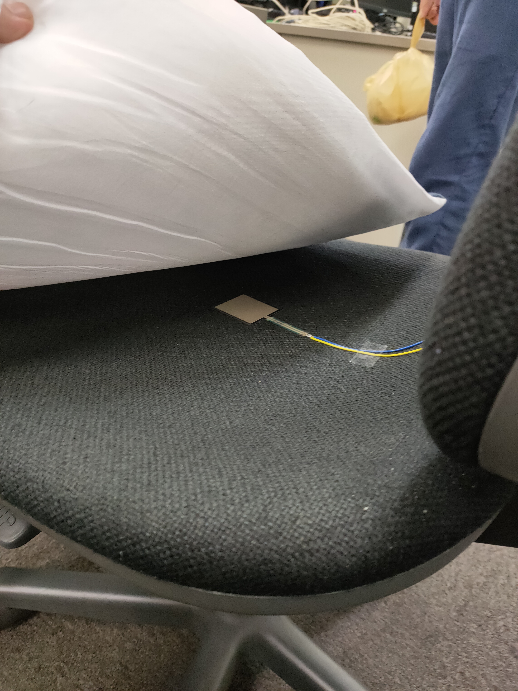
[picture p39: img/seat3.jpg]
seat3
    

## Web画面  

画面は2画面用意する  
- 閲覧者用画面  
各管理者の着席状態が見れる  
更新ボタンで着席状態を更新できる  
更新ボタンを押さなくても、3秒ごとに着席状態を自動で更新する  
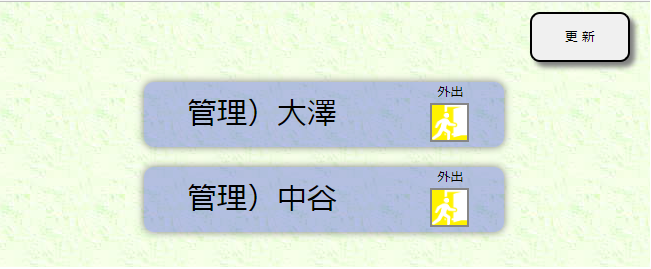
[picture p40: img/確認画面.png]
画面
  

- 管理者用画面  
閲覧者用画面にテレワークボタンを追加  
テレワークボタンを押すと、着席状態のところが「テレワーク」となり  
もう一度ボタンを押すまで、「テレワーク」状態は解除されない  
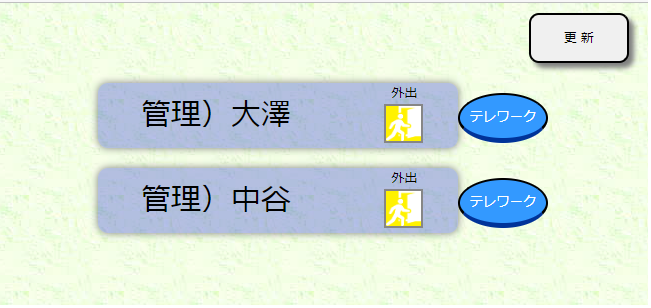
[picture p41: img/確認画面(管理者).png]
管理者画面


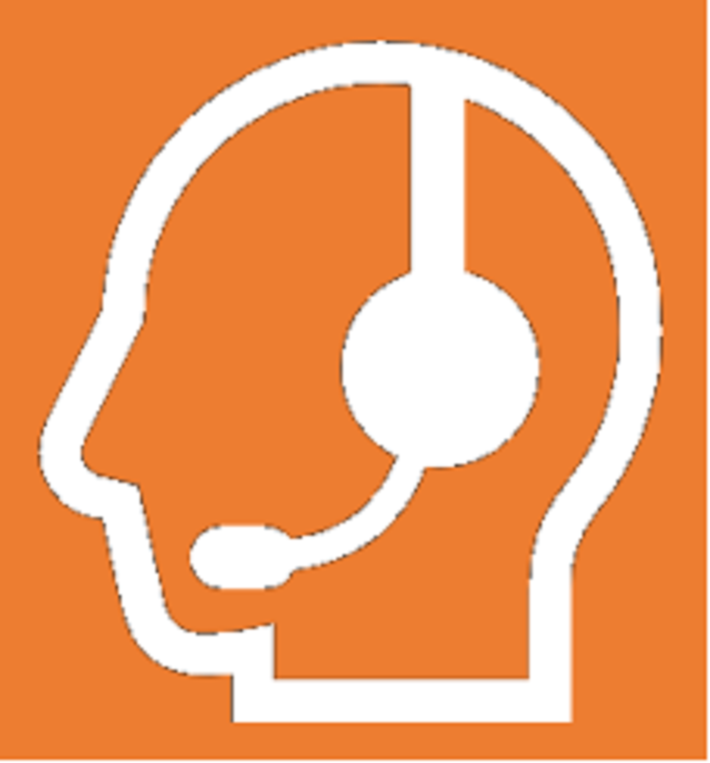
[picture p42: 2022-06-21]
ksap-seatmotion/assets/img/テレワーク.png

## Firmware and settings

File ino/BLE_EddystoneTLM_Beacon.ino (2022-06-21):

#include "sys/time.h"

#include <Arduino.h>
#include <string>

#include "BLEDevice.h"
#include "BLEUtils.h"
#include "BLEBeacon.h"
#include "BLEAdvertising.h"
#include "BLEEddystoneURL.h"

#include "esp_sleep.h"

#define GPIO_DEEP_SLEEP_DURATION 10     // sleep x seconds and then wake up
RTC_DATA_ATTR static time_t last;    // remember last boot in RTC Memory
RTC_DATA_ATTR static uint32_t bootcount; // remember number of boots in RTC Memory

// See the following for generating UUIDs:
// https://www.uuidgenerator.net/
BLEAdvertising *pAdvertising;
struct timeval nowTimeStruct;

time_t lastTenth;

const int vol_pin = 14;//圧力センサ用アナログピン

#define BEACON_UUID "8ec76ea3-6668-48da-9866-75be8bc86f4d" // UUID 1 128-Bit (may use linux tool uuidgen or random numbers via https://www.uuidgenerator.net/)

void setBeacon()
{
  uint16_t beconUUID = 0xFEAA;

  BLEAdvertisementData oAdvertisementData = BLEAdvertisementData();
  BLEAdvertisementData oScanResponseData = BLEAdvertisementData();
  
  oScanResponseData.setFlags(0x06); // GENERAL_DISC_MODE 0x02 | BR_EDR_NOT_SUPPORTED 0x04
  oScanResponseData.setCompleteServices(BLEUUID(beconUUID));
  
  char state;
  state = StateRead();

  oScanResponseData.setServiceData(BLEUUID(beconUUID), &state);
  oAdvertisementData.setName("TLMBeacon");
  pAdvertising->setAdvertisementData(oAdvertisementData);
  pAdvertising->setScanResponseData(oScanResponseData);
}

void setup()
{

  Serial.begin(115200);
  gettimeofday(&nowTimeStruct, NULL);

  Serial.printf("start ESP32 %d\n", bootcount++);

  Serial.printf("deep sleep (%lds since last reset, %lds since last boot)\n", nowTimeStruct.tv_sec, nowTimeStruct.tv_sec - last);

  last = nowTimeStruct.tv_sec;
  lastTenth = nowTimeStruct.tv_sec * 10; // Time since last reset as 0.1 second resolution counter

  // Create the BLE Device
  BLEDevice::init("TLMBeacon");

  BLEDevice::setPower(ESP_PWR_LVL_N12);

  pAdvertising = BLEDevice::getAdvertising();

}

//感圧センサの状態を読み取り、状態をreturnする
char StateRead() {
  // アナログピンの入力値を読み込み。
  int sensorValue = analogRead(vol_pin);

  // ある程度圧力が加わった場合
  if (sensorValue < 2000) {
    Serial.println("high");
    return '1';
  }
  else {
    Serial.println("low");
    return '0';
  }
}


void loop()
{
  setBeacon();
  // Start advertising
  pAdvertising->start();
  delay(3000);
}

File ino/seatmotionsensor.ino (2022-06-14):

#include <BLEDevice.h>
#include <BLEServer.h>
#include <BLEUtils.h>
#include <BLE2902.h>

BLEServer *pServer;
BLEService *pService;
BLECharacteristic *pCharacteristic;

bool deviceConnected = false;
uint8_t value = 0;

// PIN number
#define GPIOINPUT 27

// See the following for generating UUIDs:
// https://www.uuidgenerator.net/

#define SERVICE_UUID        "D5875408-FA51-4763-A75D-7D33CECEBC31"
#define CHARACTERISTIC_UUID "A4F01D8C-A037-43B6-9050-1876A8C23584"

// コールバック関数
class MyServerCallbacks: public BLEServerCallbacks {
    //ESP接続時のイベント
    void onConnect(BLEServer* pServer) {
      Serial.println("Connected!");
      deviceConnected = true;
    };

    //ESP切断時のイベント
    void onDisconnect(BLEServer* pServer) {
      Serial.println("DisConnected!");
      deviceConnected = false;
      // 再接続を行う
      pServer->getAdvertising()->start();
      Serial.println("Waiting a client connection to notify...");      
    }
};

//シリアルボードと入力ピンの設定
void doInitialize() {
  Serial.begin(115200);
  pinMode(GPIOINPUT, INPUT);  
}

void setup() {

  //初期処理
  doInitialize();
  
  //ESPのデバイス名を決定
  BLEDevice::init("ESP32_Local_Device");

  // Create the BLE Server
  pServer = BLEDevice::createServer();
  //コールバック関数の登録
  pServer->setCallbacks(new MyServerCallbacks());

  // Create the BLE Service
  pService = pServer->createService(SERVICE_UUID);

  // Create a BLE Characteristic
  pCharacteristic = pService->createCharacteristic(
                      CHARACTERISTIC_UUID,
                      BLECharacteristic::PROPERTY_READ   |
                      BLECharacteristic::PROPERTY_WRITE  |
                      BLECharacteristic::PROPERTY_NOTIFY |
                      BLECharacteristic::PROPERTY_INDICATE
                    );

  // https://www.bluetooth.com/specifications/gatt/viewer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
  // Create a BLE Descriptor
  pCharacteristic->addDescriptor(new BLE2902());

  // Start the service
  pService->start();

  // Start advertising
  //接続待ち状態となる
  pServer->getAdvertising()->start();
  Serial.println("Waiting a client connection to notify...");
}

//接続が出来たら、ループ処理に入る
void loop() {

  if (deviceConnected) {
    
    //人感センサからの入力がある場合
    if (digitalRead(GPIOINPUT) == 1){
      //1を送信
      pCharacteristic->setValue("1");
      pCharacteristic->notify();
      Serial.println(1);
    //人感センサからの入力がない場合
    }else{
      //0を送信
      pCharacteristic->setValue("0");
      pCharacteristic->notify();
      Serial.println(0);
    }
    
  } 
  delay(1000);
}
